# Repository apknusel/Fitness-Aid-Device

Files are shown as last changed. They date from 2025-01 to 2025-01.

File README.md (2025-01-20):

# Wearable Fitness Tracker
## Project Overview
The Wearable Fitness Tracker is a wearable device designed to assist users in monitoring workout intensity and performance. It combines real-time data from a pulse oximeter and a muscle sensor to evaluate heart rate, blood oxygen levels, and muscle engagement. This data is transmitted via Bluetooth Low Energy (BLE) to a web application ([static version of web app](https://apknusel.github.io/WorkoutTracker/)), enabling users to track their exercise sessions efficiently.

## Motivation
The motivation behind this project is trying to find a better way to determine how hard someone is pushing themself while working out. I have seen a lot of people try accelerometers and force sensor to determine how hard someone is working out, but never anyone trying to look at the actual muscle. This was the goal of my project by working with the muscle sensors.

## Key Features
- **Heart Rate and Blood Oxygen Monitoring**: Uses the MAX30102 pulse oximeter for real-time heart rate and SpO2 measurement.
- **Muscle Activity Tracking**: Employs the MyoWare muscle sensor to gauge muscle engagement during exercises.
- **State-Based Operation**: Finite state machine controls device operations with intuitive feedback using a multicolor LED and a vibration motor.
- **Web-Based Interface**: BLE communication with a web application for visualizing and recording fitness data.

## Components

### [Myoware 2.0 Muscle Sensor](https://www.sparkfun.com/products/21265)
- Used for collecting the muscle data. I had to solder one three wires because I was not using a HAT with the device.

### [Vibration Motor](https://www.sparkfun.com/products/8449)
- Used for giving the user feedback to allow the user to use their hands while lifting and not for focusing on the device.

### [MAX30102 Pulse Oximeter](https://www.amazon.com/MAX30102-Detection-Concentration-Compatible-Arduino/dp/B07ZQNC8XP)
- Used for calculating the heart rate and blood oxygen of the person wearing the device

## Circuit Diagram
circuit diagram

## Finite State Machine
The project is designed around a finite state machine with distinct states
- **ON**: Idle state awaiting user input.
- **INITIALIZATION**: Calibrates muscle sensor for baseline readings.
- **READING**: Records muscle engagement data.
- **HRBO**: Measures heart rate and blood oxygen.
- **TRANSMIT**: Sends collected data to the web application.

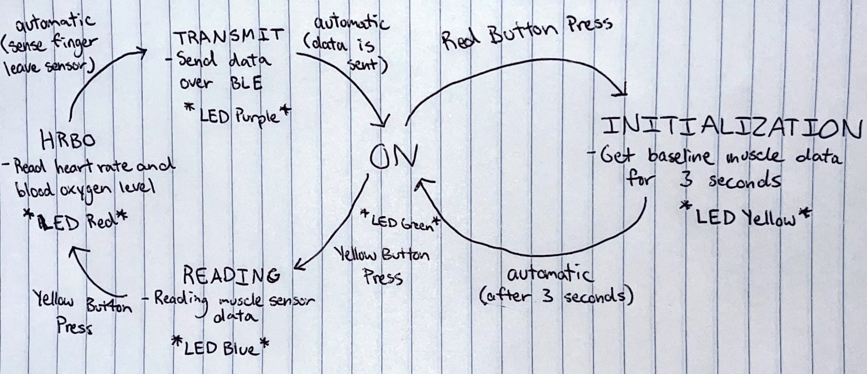
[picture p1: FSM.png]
finite state machine


## Images
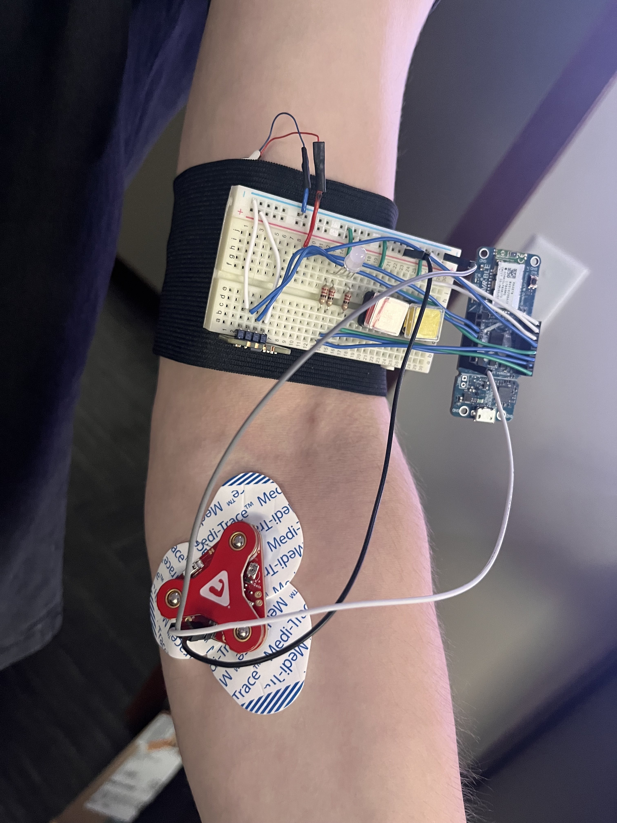
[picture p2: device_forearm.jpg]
device on forearm

device

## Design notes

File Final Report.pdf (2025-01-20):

Alex Knusel

# Final Report: Wearable Fitness Device

## CSCI 5143 - Fall 2024

# Introduction

## What is it?

My project is a fitness device that will aid people in working out by collecting data from various sensors and presenting it in a digestible format for the user. The data collected is from a pulse oximeter (to read heart rate and blood oxygen) and a muscle sensor (to determine a set's percent difficulty or effort). This data is passed into a web application where a user can keep track of the sets and reps for an exercise while the device automatically fills out the heart rate, blood oxygen, time, and percent difficulty. The device aims to answer the question: How hard am I working out? By giving the user easy-to-digest data that can assist in adjusting workouts to get the most out of the time spent at the gym.

## Embedded Systems Relevance

This project showcases the unique characteristics of embedded systems by leveraging their core principles to achieve functionality that distinguishes them from general-purpose desktop computers. Unlike a desktop computer, which is designed for a broad range of tasks, this system is purpose-built for specific applications with a focus on portability, power efficiency, and resource optimization. It incorporates BLE communication, an ADC, and I2C communication with external peripherals, all of which are essential for achieving real-time performance and seamless integration with hardware components. Interrupts for buttons and real-time tracking enhance the system’s responsiveness, enabling immediate interaction with users in ways that a desktop computer cannot efficiently replicate for such specialized tasks.
The use of external peripherals, guided by datasheet interpretation, further showcases the embedded system's adaptability within constrained environments. The system’s compact and portable design makes it more suitable for field use or wearable technology, which would be impractical with a larger computer. Additionally, I incorporated signal processing techniques, such as a DC Estimator and FIR Filter, to process pulse oximeter readings directly on the device, eliminating the need for a full-scale processing system. To extend its functionality, I utilized Node.js to create a lightweight web server for hosting a web application that communicates with the embedded system, bridging the gap between the device and broader networked ecosystems. This holistic approach demonstrates the embedded system's ability to deliver specialized, efficient, and user-friendly solutions in ways that general-purpose computers are not designed to achieve.

# Design and Implementation

## Circuit Diagram

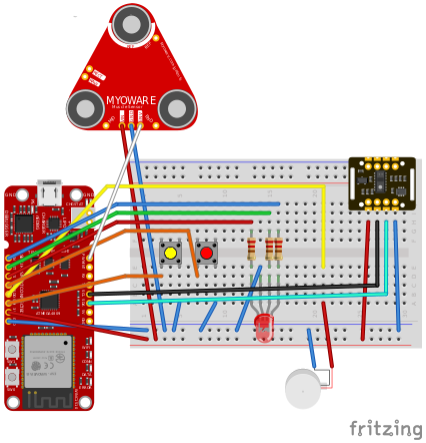
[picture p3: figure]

## Component Connections

### MAX30102 Pulse Oximeter

The MAX30102 pulse oximeter has four pins and uses the I2C communication protocol. The VIN pin is for voltage input, the SDA pin is for serial data, the SCL pin is for the serial clock, and the GND pin is for ground. The peripheral runs on 3.3V per the datasheet.

MAX30102 Pins | AVR-BLE Pins | Diagram Wire Color
VIN | 3.3V | Red
SDA | PA2 (SDA) | Black

SCL | PA3 (SCL) | Teal
GND | GND | Blue

### Multicolor LED

The multicolor LED has four pins: a GND pin for ground and then three pins for controlling the red, green, and blue light intensity based on the current in the circuit. These three pins are also connected to a 220-ohm resistor.

Multicolor LED Pins | AVR-BLE Pins | Diagram Wire Color
Single Leg (Next to Longesr Middle Leg) | D7 | Red
GND (Longest) | GND | GND
Middle Pin (Not Longest) | D5 | Green
Outer Pin (Next to Shorter Middle Leg) | A7 | Blue

### Buttons

There are two buttons, a red button and a yellow button, that are sensed on the rising edge with the internal pullup resistors enabled on the pins. Each button has two pins, one for GPIO and the other for GND.

Button Pins | AVR-BLE Pins | Diagram Wire Color
Red Button - GPIO Pin | A6 | Orange Wire
Red Button - GND | GND | Blue Wire
Yellow Button - GPIO Pin | A4 | Orange Wire
Yellow Button - GND | GND | Blue Wire

### Myoware Muscle Sensor

There are many different pins and configurations for the Myoware Muscle Sensor, but I am connecting to the GND, VIN, and ENV pins on the peripheral. I soldered pins onto the Myoware Muscle Sensor in the location seen in the diagram to connect wires to the board. The power for this peripheral is 3.3V per the datasheet. The ENV pin needs to be connected to a pin that can receive an analog signal, which D1 is capable of. The ENV pin sends the analog signal of the muscle readings from the muscle sensor to the AVR-BLE board.

Muscle Sensor Pins | AVR-BLE Pins | Diagram Wire Color
VIN | 3.3V | Red
GND | GND | Blue
ENV | D1 | White

### Vibration Motor

The vibration motor has two cables attached to it, and I soldered on thicker, longer cables to make it easier to work with. These two wires are GND and VIN.

Vibration Motor Pins | AVR-BLE Pins | Diagram Wire Color
VCC | A5 | Red and Yellow
GND | GND | Blue

## Hardware Setup

My hardware setup uses a few different components of the AVR-BLE board and a few external peripherals. The overall layout of the project is a finite state machine, as shown above, where button presses or an amount of time passing transitions between states. To do this, I used interrupts for button presses on PORTA, and I used the RTC timer with an overflow that triggered at a rate of 1024 Hz, which increases a milliseconds variable by 1000. This is paired with a macro directly accessing the RTC.CNT register and adding that to milliseconds to accurately track time. This is almost perfect, but not quite because RTC.CNT will increment up to 1024 before being reset to 0. That means that if the milliseconds macro is called in the worst case it can be 24 milliseconds off. But once the overflow occurs it resets the RTC.CNT so it will not get less accurate as time goes on. The MAX30102 (pulse oximeter) peripheral is communicated with using I2C communication, and the muscle sensor outputs an analog signal, which the ADC processes. When in the respective state, the functions for interfacing with these devices are called, and data is read in to be transmitted over BLE to the web application later on. When transitioning between states, a short delay gives the user ample time to prepare for the next state. Each state will set the multicolor LED to the color of the respective state, and transitioning between states causes the vibration motor to vibrate so the user does not need to look at the device. The device can be connected to the web application at any point in time, but if it is not connected, it will not send the data anywhere.

If the device is connected to the web application, when the device is in the transmit state, it will send the data to the web app, where the selected row will be populated with the data.

## Hardware Setup Reasoning

There are quite a few reasons why I chose this setup over potential alternatives. I went with using a finite state machine because it is relatively simple to understand and allows for much planning. In this case, the planning was super important because many of my parts did not come until later, so it gave me something to work on while waiting for my parts. I decided to use BLE communication with a web application because it would’ve been very difficult to use a screen or some other medium to display data to the user, especially on a wearable device. Also, the web application is extremely versatile and allows for a database to be hooked up to store data in the future. I also used the web application to test my sensors and understand the data from the external peripherals through graphs. I went with the multicolor LED and vibration sensor because they are both relatively inexpensive, simple components that give the right amount of information to the user. The vibration motor was crucial to making the wearable device reasonable to use while working out because it allows the user to get feedback without looking at the device. This means that after the user presses the button to enter the reading state, they have the vibration to tell them when they can start their exercise to get the most accurate sensor and timer reading. I mainly went with the Myoware muscle sensor because it was the most accessible device to use (cheapest, and there are very few muscle sensors out there). I also originally intended to use it with a HAT that allows it to communicate over BLE, but this was not in stock when ordering parts. Instead, I soldered directly onto the board and used it that way. I looked at a few alternatives, such as using more primitive electronic components to make a “DIY” muscle sensor, but I did not have the electrical experience to carry that out. I decided to use the MAX30102 muscle sensor because it used the I2C protocol and allowed me to do post-processing on the data. However, it had enough QOL features, like a circular buffer, to store a few samples and keep things somewhat simple. This has allowed me to learn a lot more compared to if I used something like the SparkFun Pulse Oximeter and Heart Rate Sensor - MAX30101 & MAX32664 (Qwiic) because a device like this would abstract away the raw data such as IR, red, and green values read by the sensor and only give me the calculated bpm and blood oxygen. I wanted to do these calculations by myself to learn something new.

## Finite State Machine

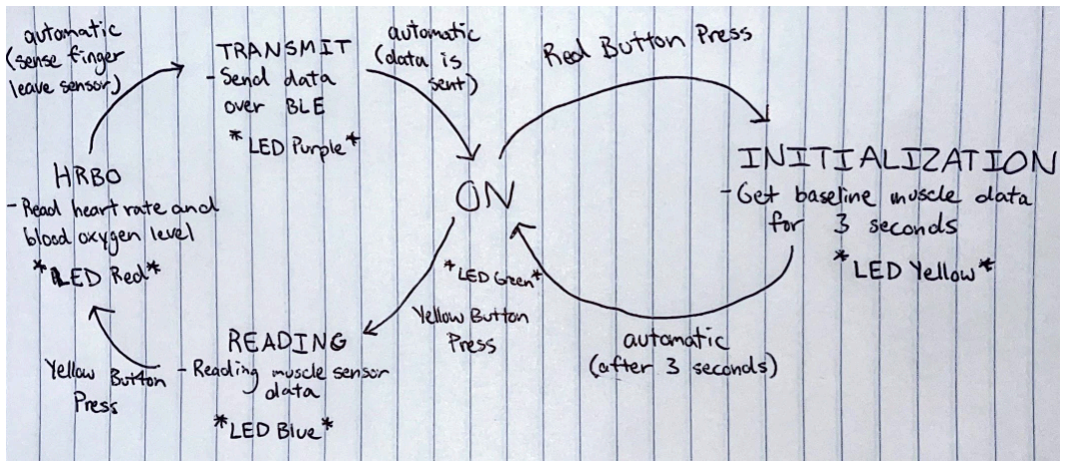
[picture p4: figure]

## Software Key Objectives

- Sensor Data Collection: The software interacts with sensors like the MAX30102 for heart rate and blood oxygen measurement and a muscle sensor for tracking muscle activity. The software needs to be able to read data from these sensors efficiently and timely.
- State Management: The device operates in different states (e.g., ON, INITIALIZATION, READING, HRBO, TRANSMIT), with transitions triggered by button presses or time conditions.
- BLE Communication: The software communicates using the BLE module to send collected data to a web application, enabling monitoring of fitness data. The external web application software needs to be able to accept the data and display it in a userful and convenient way to the user.
- Vibration and LED Control: The device uses vibration to provide feedback to the user and LEDs to indicate the device's current state. The device needs to be able to signal state changes for the user to perform the proper actions in each state in a timely manner.
- Real-time Clock (RTC): The software needs to keep track of time, which is necessary for time-based operations like measuring heart rate intervals or controlling state transitions. This will be an extremely important part of the software that has to be reliable for the device to function properly.
- Web Application: An additional piece of software, the web application, needs to be able to receive information and display it to the user in a digestible format.

## Software Design

- Main Loop: The core loop of the software constantly checks for state changes, manages transitions, collects data, and communicates with the BLE module. It also handles feedback mechanisms like vibrations and LED updates. This paired with the RTC timer allows for timely transitions and correct functioning of the device in each state.
- Interrupts: Various interrupts are used
- Button Press Interrupts: Detect button presses to trigger state transitions.
- RTC Overflow Interrupt: Keeps track of elapsed time by dividing the internal clock that runs at 32.768 kHz by 32 to get a rate of 1.024 kHz. This is as close as you can get the clock to be to 1 kHz which would be ideal for keeping track seconds. I set the RTC.PER value to 1024 so that every second there will be an interrupt. When the interrupt occurs 1000 is added to the milliseconds variable. There is then a micro called millis() defined that adds the milliseconds variable to RTC.CNT to get a relatively accurate number of milliseconds passed since startup. This number was accurate enough for me from what I tested. In the worst-case scenario, this number could be off up to 24 milliseconds because 1 RTC.CNT is equivalent to 0.976 milliseconds instead of 1 millisecond.
- State Management: The device has a state machine (device_state_t) to manage transitions between states such as ON, INITIALIZATION, READING, HRBO, and TRANSMIT.
- ON: This is the initial state of the device and is essentially the waiting state for a button press to transition to a more interesting state.
- INITIALIZATION: Takes a 3 seconds reading of the muscle sensor to get a baseline for future calculations involving the muscle sensor.
- READING: Takes in the data from the muscle sensor and computes a running average of the readings for calculating the percent difficulty.
- HRBO: Takes in data from the MAX30102 pulse oximeter and does calculations to compute the heart rate and blood oxygen.
- TRANSMIT: Sends the heart rate, blood oxygen, percent difficuilty, and time elapsed over BLE to the web application.
- Sensor Data Handling:
- The MAX30102 is used for heart rate and blood oxygen measurement via I2C. It reads in the red and IR values and then uses a DC estimator, FIR filter, and a heart rate and blood oxygen algorithm to calculate the heart rate and blood oxygen.
- The muscle sensor uses ADC to measure muscle activity, and the software processes this data using a running average to determine the intensity of the workout.
- BLE Communication:
- The USART and BLE communication functions are used to initialize the BLE module, send commands, and transfer sensor data over BLE. The BLE module is running the Fitness Machine Service and Physical Activity Level Characteristic which the web application searches for when looking for BLE devices. The characteristic is set with the properties Write, Write Without Response, and Notify.
- Data is sent to the web application in chunks of 8 bytes where each value is 2 bytes long, with each sensor's reading packaged and transmitted through the BLE_send_data function.
- Web Application: The web application receives the chunks of data sent over BLE and applies them to the proper rows associated with that exercise the user is currently doing. This is done by allowing the user to select the row associated with their current exercise. Then, that row is automatically populated when the data is sent.

## Technical Challenges

This project had quite a few technical challenges that needed to be solved. The first of these was how to keep track of time in the software down to milliseconds to do calculations involving heart rate, blood oxygen, and other time-dependent calculations. I used the RTC timer to keep track of elapsed time by dividing the internal clock that runs at 32.768 kHz by 32 to get a rate of 1.024 kHz. This is as close as you can get the clock to be to 1 kHz which would be ideal for keeping track seconds. I set the RTC.PER value to 1024 so that every second there will be an interrupt. When the interrupt occurs 1000 is added to the milliseconds variable. There is then a micro called millis() defined that adds the milliseconds variable to RTC.CNT to get a relatively accurate number of milliseconds passed since startup. This number was accurate enough for me from what I tested. In the worst-case scenario, this number could be off up to 24 milliseconds because 1 RTC.CNT is equivalent to 0.976 milliseconds instead of 1 millisecond.
The second technical challenge needed to be addressed was calculating the heart rate and blood oxygen. I took inspiration from a C++ Arduino Library (https://github.com/sparkfun/SparkFun_MAX3010x_Sensor_Library)

1
for a MAX3010X Sensor to calculate heart rate and adjusted the IR_AC and threshold values to get more accurate readings based on the received data. Calculating heart rate is very difficult, and many external factors can affect the readings. For example, someone's skin color can affect the accuracy of the readings because darker colors absorb more red light. I tuned in the data to calculate my heart rate by graphing the data I received (red value, IR value, and calculated heart rate) while also looking at my Apple Watches heart rate reading. I would adjust the IR_AC values used in the calculations and the thresholds until I got relatively accurate readings. To calculate blood oxygen (SpO2), I followed an article, Oxygen Saturation - SpO2 Measurement (https://community.element14.com/technologies/medical/b/blog/posts/oxygen-saturation---spo2-measurement)

2
, which
detailed some of the higher-level concepts, and then I applied them to my code. I decided not to follow the MAX3010X Arduino libraries method because I wanted to apply what I learned from calculating the heart rate and because blood oxygen was less important data for the user.
Another technical challenge was understanding the muscle sensor readings. This was a challenge for a multitude of reasons. The first reason was that the muscle sensor advertises that it can pick up a wide range of signals based on how much the muscle is flexed, but after testing it myself and reading some discussions online, I realized this is not the case. The muscle can only really reliably tell if a muscle is flexed or not. This, paired with the fact that I was not using a HAT with the sensor, made the data very difficult to read, so I had to interpret the data more similarly to a binary value. This was fine for my application, and I used a running average. After testing the device while working out, the difficulty felt relatively accurate to how I felt after the exercise. Ideally, I would have used a HAT with the device to get the most accurate readings, but the HAT has been out of stock while working on the device.
The last technical challenge I faced was creating an application for the device to communicate with. I messed around with doing this in Python, which I was able to receive data in, but creating a user interface had a large learning curve. This, paired with the overhead and installation process for running the app, made it seem less practical for the average user (one of my goals being to make the device so anyone could use it). My second option was to look at if web browsers support BLE. Fortunately, after reading the following article, Communicating with Bluetooth devices over JavaScript (https://developer.chrome.com/docs/capabilities/bluetooth)

3
, I discoverd they do
and could begin writing code. I hadn’t used JavaScript before this, so I spent some time learning the basics, but eventually, I got the web application working. I decided to use Node.js and Express to run the server and later discovered the simplest solution to allow someone to use the device. This solution was to host the JavaScript application statically on GitHub Pages and allow anyone to test the device at https://apknusel.github.io/WorkoutTracker/

4

# Final Product

## Final Product Pictures

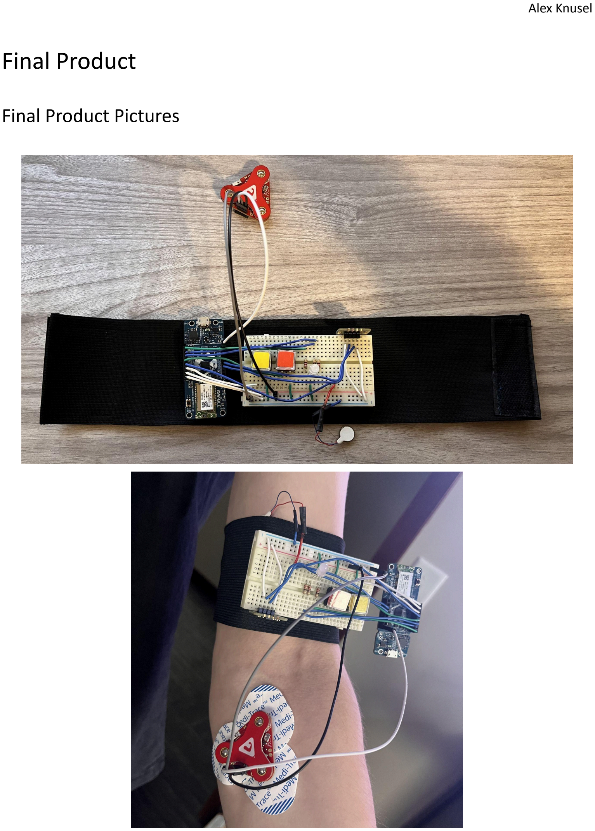
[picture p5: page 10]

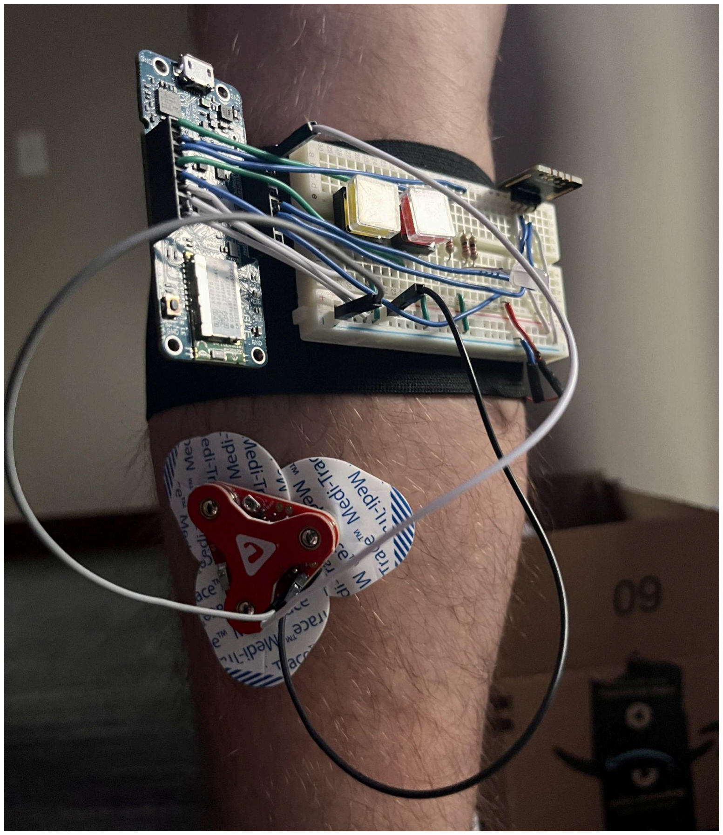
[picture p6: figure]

In the pictures above you can see the device standalone, being worn on the forearm muscle, and being worn on the calf muscle. I managed to get the device to be worn just about everywhere using the black velcro strap and then for larger areas of the body (e.g. across the chest) I could daisy chain together the black straps.

## What is it and How to Use it?

Like I stated earlier in this document the device is a wearable fitness aid the reads in data from a muscle sensor and pulse oximeter and then relays the data over BLE to a web app where a user can track their exercises. This device is designed to allow people to be more efficient with their workouts in the gym and understand if they are working out hard enough. This is important because figuring out if you are working out hard enough is a really difficult task for even some of the most experienced lifters. This is an attempt at solving that problem.
The first step to use the device would be putting on the device which can be done by wrapping the black band on your body near the muscle group you are working out. Then you should attach three EMG/ECG pads to the myoware muscle sensor and figure out based on this guide (https://cdn.sparkfun.com/assets/learn_tutorials/1/9/5/6/MyoWare_v2_AdvancedGuide-Updated.pdf)

5 where to place the
sensor for the muscle you are exercising. Once the sensor is placed on the muscle you can plug in the device to a portable charger using a micro-usb cable to connect to the device. This will power on the device and put it in the ON state. After this, you will open up the fitness tracker and connect the device by entering the device name in the top left. By default this name is FitDev and you will be prompted to select the device and hit pair. Once the device is paired the tracker will display a green disconnect button and you are ready to start working out. Click add exercise on the website and put in the exercise and number of reps you will be doing. Click the select button on that row and it will turn red indicating you selected the row. You will then press the red button on the device and 3 seconds will pass and then you will feel a vibration. Once you feel the vibration you will flex the muscle as hard as you can until you feel another vibration. Once this has finished you get ready to do the exercise for the muscle the sensor is on. Now press the yellow button and once you feel a vibration begin the exercise. Once you are finished with the exercise press the yellow button and place your finger on the pulse oximeter. Once you feel a vibration your heart rate blood oxygen will be read. Leave your finger on the sensor for around 10 seconds or longer for a more accurate reading. Once you finger leaves the sensor 3 seconds will pass and the data will be sent to the web app. If you are switching exercises you will need to repeat the initialization phase by pressing the red button, otherwise you can press the yellow button and select the next row.

## Goals

There were quite a few goals I was able to achieve while working on this project. The first of those goals was creating a functional and simple way to receive data from the device in the style of a fitness tracker. I was able to achieve this goal which can be seen by the functioning web app I created. The second goal I had was to perfect the communication with the MAX30102 pulse oximeter. This was a goal of mine because from reading the datasheet the peripheral was pretty complex. I was able to not only achieve this goal but exceed it by adjusting the algorithms I used for calculating heart rate and blood oxygen to be more accurate. My third goal was to create a form factor that was reasonable to wear while working out. I was able to achieve this goal, but I wish I had more time to 3D print a box for my board and peripherals to make it look more professional.
There were a few initial goals for my project that I did not meet. The first of these goals was to use the accelerometer to collect data as well. I did test this feature and tried to analyse the data in a way that was meaningful to the user. I was not able to figure out a way to do this because every exercise is different and the data didn’t have any real meaning because any exercise could be performed with the device. The second goal I did not meet was making the device extremely accurate. This was a really difficult task and I imagine having some biomedical engineering background could have helped me. I was able to get the blood oxygen very accurate, but the heart rate was ±4 bpm at times when comparing with my Apple Watch readings.

# Reflection

Knowing what I know know now I would’ve made a few changes to the device. The first change I would’ve made is using a more accurate sensor similar to the one another group used when calculating heart rate and blood oxygen. The sensor they had used both fingers and gave much more accurate red and ir values for calculating heart rate and blood oxygen. The second thing I would change is the way I got data from the muscle sensor. Instead of soldering to the ENV, VIN, and GND pins I would’ve used the HAT or instead opted for another approach such as making my own muscle sensor. This would’ve made the data received from the peripheral a lot less noisy.
If I had more time I would focus on making my device more accurate. To make the device more accurate I would try to look at more recent research on calculating heart rate and blood oxygen and implement those algorithms. Another thing I would do to extend the final product would be to reduce the number of buttons or remove them entirely. The buttons were fine, but I think that it would feel much more natural if there was some other mechanism that was more seamless. Maybe even clicking buttons in the web app instead. Lastly, I had begun working on putting the device to sleep in the ON state until a button interrupt occured to switch to another state to try to reduce power consumption, but I have not got that fully working yet.

# References

1. https://github.com/sparkfun/SparkFun_MAX3010x_Sensor_Library
2. https://community.element14.com/technologies/medical/b/blog/posts/oxygen-saturation---spo 2-measurement (https://community.element14.com/technologies/medical/b/blog/posts/oxygen-saturation---spo2-measurement)
3. https://developer.chrome.com/docs/capabilities/bluetooth
4. https://apknusel.github.io/WorkoutTracker/
5. https://cdn.sparkfun.com/assets/learn_tutorials/1/9/5/6/MyoWare_v2_AdvancedGuide-Update d.pdf (https://cdn.sparkfun.com/assets/learn_tutorials/1/9/5/6/MyoWare_v2_AdvancedGuide-Updated.pdf)

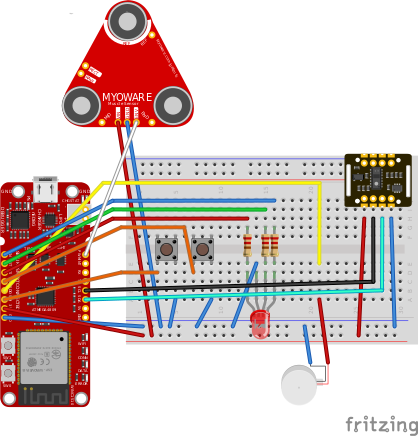
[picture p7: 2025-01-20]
circuit_diagram.png

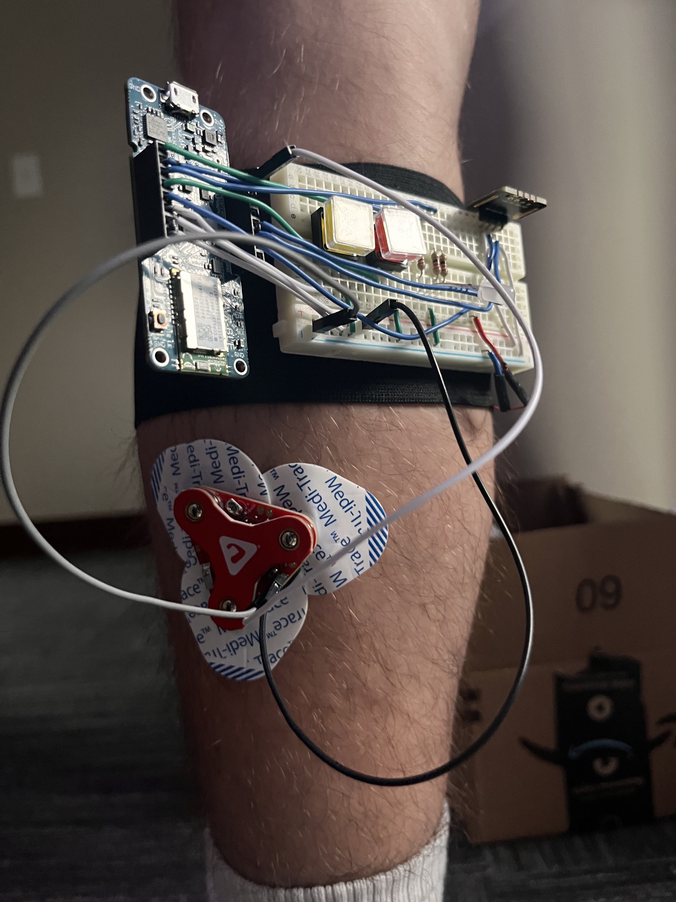
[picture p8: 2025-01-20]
device_calf.jpg

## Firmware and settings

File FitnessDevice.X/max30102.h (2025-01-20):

#ifndef F_CPU
#define F_CPU 3333333
#endif

#include <avr/io.h>
#include <util/delay.h>
#include <stdlib.h>
#include <string.h>
#include <stdio.h>
#include <avr/interrupt.h>
#include "max30102_math.h"

#ifndef MAX30102_H
#define	MAX30102_H

// Definitions for the memory locations on the MAX30102 and valid values
#define MAX30102_I2C_ADDR 0x57

// Constants for default settings
#define DEFAULT_POWER_LEVEL 0x1F
#define DEFAULT_SAMPLE_AVG 4
#define DEFAULT_LED_MODE 3
#define DEFAULT_SAMPLE_RATE 50
#define DEFAULT_PULSE_WIDTH 69
#define DEFAULT_ADC_RANGE 16384

#define MAX30102_FIFO_DATA 0x07

// Status Registers
#define MAX30105_INTSTAT1 0x00
#define MAX30105_INTSTAT2 0x01
#define MAX30105_INTENABLE1	0x02
#define MAX30105_INTENABLE2 0x03

// FIFO Registers
#define MAX30105_FIFOWRITEPTR 0x04
#define MAX30105_FIFOOVERFLOW 0x05
#define MAX30105_FIFOREADPTR 0x06
#define MAX30105_FIFODATA 0x07

// Configuration Registers
#define MAX30105_FIFOCONFIG 0x08
#define MAX30105_MODECONFIG 0x09
#define MAX30105_PARTICLECONFIG 0x0A
#define MAX30105_LED1_PULSEAMP 0x0C
#define MAX30105_LED2_PULSEAMP 0x0D
#define MAX30105_LED3_PULSEAMP 0x0E
#define MAX30105_LED_PROX_AMP 0x10
#define MAX30105_MULTILEDCONFIG1 0x11
#define MAX30105_MULTILEDCONFIG2 0x12

#define MAX30105_DIETEMPINT 0x1F
#define MAX30105_DIETEMPFRAC 0x20
#define MAX30105_DIETEMPCONFIG 0x21

#define MAX30105_PROXINTTHRESH 0x30

#define MAX30105_REVISIONID 0xFE
#define MAX30105_PARTID 0xFF

// MAX30105 Commands
#define MAX30105_INT_A_FULL_MASK 0b10000000
#define MAX30105_INT_A_FULL_ENABLE 0x80
#define MAX30105_INT_A_FULL_DISABLE 0x00

#define MAX30105_INT_DATA_RDY_MASK 0b01000000
#define MAX30105_INT_DATA_RDY_ENABLE 0x40
#define MAX30105_INT_DATA_RDY_DISABLE 0x00

#define MAX30105_INT_ALC_OVF_MASK 0b00100000
#define MAX30105_INT_ALC_OVF_ENABLE 0x20
#define MAX30105_INT_ALC_OVF_DISABLE 0x00

#define MAX30105_INT_PROX_INT_MASK 0b00010000
#define MAX30105_INT_PROX_INT_ENABLE 0x10
#define MAX30105_INT_PROX_INT_DISABLE 0x00

#define MAX30105_INT_DIE_TEMP_RDY_MASK 0b00000010
#define MAX30105_INT_DIE_TEMP_RDY_ENABLE 0x02
#define MAX30105_INT_DIE_TEMP_RDY_DISABLE 0x00

#define MAX30105_SAMPLEAVG_MASK 0b11100000
#define MAX30105_SAMPLEAVG_1 0x00
#define MAX30105_SAMPLEAVG_2 0x20
#define MAX30105_SAMPLEAVG_4 0x40
#define MAX30105_SAMPLEAVG_8 0x60
#define MAX30105_SAMPLEAVG_16 0x80
#define MAX30105_SAMPLEAVG_32 0xA0

#define MAX30105_ROLLOVER_MASK 0xEF
#define MAX30105_ROLLOVER_ENABLE 0x10
#define MAX30105_ROLLOVER_DISABLE 0x00

#define MAX30105_A_FULL_MASK 0xF0

#define MAX30105_SHUTDOWN_MASK 0x7F
#define MAX30105_SHUTDOWN 0x80
#define MAX30105_WAKEUP 0x00

#define MAX30105_RESET_MASK 0xBF
#define MAX30105_RESET 0x40

#define MAX30105_MODE_MASK 0xF8
#define MAX30105_MODE_REDONLY 0x02
#define MAX30105_MODE_REDIRONLY 0x03
#define MAX30105_MODE_MULTILED 0x07

#define MAX30105_ADCRANGE_MASK 0x9F
#define MAX30105_ADCRANGE_2048 0x00
#define MAX30105_ADCRANGE_4096 0x20
#define MAX30105_ADCRANGE_8192 0x40
#define MAX30105_ADCRANGE_16384 0x60

#define MAX30105_SAMPLERATE_MASK 0xE3
#define MAX30105_SAMPLERATE_50 0x00
#define MAX30105_SAMPLERATE_100 0x04
#define MAX30105_SAMPLERATE_200 0x08
#define MAX30105_SAMPLERATE_400 0x0C
#define MAX30105_SAMPLERATE_800 0x10
#define MAX30105_SAMPLERATE_1000 0x14
#define MAX30105_SAMPLERATE_1600 0x18
#define MAX30105_SAMPLERATE_3200 0x1C

#define MAX30105_PULSEWIDTH_MASK 0xFC
#define MAX30105_PULSEWIDTH_69 0x00
#define MAX30105_PULSEWIDTH_118 0x01
#define MAX30105_PULSEWIDTH_215 0x02
#define MAX30105_PULSEWIDTH_411 0x03

#define MAX30105_SLOT1_MASK 0xF8
#define MAX30105_SLOT2_MASK 0x8F
#define MAX30105_SLOT3_MASK 0xF8
#define MAX30105_SLOT4_MASK 0x8F

#define SLOT_NONE 0x00
#define SLOT_RED_LED 0x01
#define SLOT_IR_LED 0x02
#define SLOT_GREEN_LED 0x03
#define SLOT_NONE_PILOT 0x04
#define SLOT_RED_PILOT 0x05
#define SLOT_IR_PILOT 0x06
#define SLOT_GREEN_PILOT 0x07

#define MAX30105_EXPECTEDPARTID 0x15

// Size of buffer for storing samples
#define RATE_SIZE 4

// Struct for collecting sensor data
typedef struct {
    uint32_t ir;
    uint32_t red;
    uint32_t green;
} MAX30102_sample_t;

void MAX30102_bitMask(uint8_t reg, uint8_t mask, uint8_t value);
void MAX30102_softReset();
void MAX30102_setup();
void MAX30102_init();
void MAX30102_buffer_data(uint8_t toGet, uint8_t *buffer);
uint8_t MAX30102_readRegister8(uint8_t reg);
void MAX30102_writeRegister8(uint8_t reg, uint8_t value);
void MAX30102_get_sample(MAX30102_sample_t *sample);
void MAX30102_clearFIFO();
void RTC_init(void);

#endif	/* MAX30102_H */

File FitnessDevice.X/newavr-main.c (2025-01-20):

#ifndef F_CPU
#define F_CPU 3333333
#endif

#include "newavr-main.h"

// Variable that holds the state of the device
volatile device_state_t device_state;

// Variables to implement delay between states and vibration
volatile uint32_t button_press_time = 0; // Time of the button press
volatile bool state_change_pending = false; // Flag for pending state change
volatile device_state_t next_state; // Holds the next state to switch to
volatile uint32_t vibrate_start_time = 0; // Time for when the vibration starts
volatile bool is_vibrating = false; //  Flag for vibration
volatile bool automatic_transition = 0; // Flag for automatic transitions

// Variables for muscle sensor data
volatile uint32_t initialization_start_time = 0; // Start time of the INITIALIZATION state
volatile uint32_t muscle_sum = 0; // Sum of muscle sensor readings
volatile uint32_t muscle_samples = 0; // Number of muscle sensor samples
volatile uint32_t baseline_muscle_average = 0; // Baseline average muscle reading
volatile uint32_t muscle_average = 0; // Average muscle reading

// Variables for calculating heart rate
volatile float average_bpm = 0; // Average beats per minute
volatile float blood_oxygen = 0; // Average blood oxygen level
volatile long lastBeat = 0; // Time since the last beat
volatile float beatsPerMinute = 0; // Current beats per minute
volatile uint8_t rates[RATE_SIZE] = {0}; // Buffer for averaging
volatile uint8_t rateSpot = 0; // Index in rates buffer
volatile uint32_t ir_start_time = 0; // Time when red value exceeded threshold
volatile bool ir_below_threshold = false; // Tracks if red value is above threshold

// Buffer for storing the data to send over BLE
volatile uint16_t data_to_send[4];

// Amount of time in the READING state
volatile uint32_t reading_time = 0;

// Variable to hold milliseconds since startup
volatile uint32_t milliseconds = 0;

/**
* Initialize the vibrating peripheral
*/
void vibration_init() {
   PORTA.DIR |= PIN5_bm;
}

/**
* Starts the vibrating peripheral
*/
void start_vibration() {
   PORTA.OUTSET = PIN5_bm; // Set A5 high
   vibrate_start_time = millis();  // Record the start time
   is_vibrating = true; // Mark vibration as active
}

/**
* Checks if the device is vibrating and cancels it after 500 ms
*/
void check_vibrate() {
   if (is_vibrating) {
       // Check if 500 ms have elapsed
       if (millis() - vibrate_start_time >= 500) {
           PORTA.OUTCLR = PIN5_bm; // Set A5 low (turn off output)
           is_vibrating = false; // Reset the state
       }
   }
}

/**
* Initializes the RTC timer
*/
void RTC_init(void) {
   // Select RTC clock source
   RTC.CLKSEL = RTC_CLKSEL_INT32K_gc;

   // Configure RTC: Enable, run in standby, prescaler = 32 so 1024 Hz
   RTC.CTRLA = RTC_PRESCALER_DIV32_gc | RTC_RUNSTDBY_bm | RTC_RTCEN_bm;

   // Enable overflow interrupt
   RTC.INTCTRL = RTC_OVF_bm;

   // Start from zero
   RTC.CNT = 0;
   
   // Interrupt every second
   RTC.PER = 1024;
}

/**
* Collects the muscle data from the muscle sensor peripheral
* @param average holds the average reading for the muscle sensor
* @param timed if the function should run for 3 seconds or until state change
*/
void collect_muscle_data(uint32_t *average, bool timed) {
   // Start initialization process
   if (initialization_start_time == 0) {
       initialization_start_time = millis(); // Record the start time
       muscle_sum = 0;
       muscle_samples = 0;
   }


   // If timed is true and 3 seconds have elapsed, finalize data collection,
   // otherwise a button press will end this looping
   if (timed && millis() - initialization_start_time >= 3000) {
        if (muscle_samples > 0) {
            *average = muscle_sum / muscle_samples; // Update the variable passed as an argument
            set_LED_color(0, 1, 0);
            start_vibration();
        } else {
            *average = 0; // Set to 0 if no samples were collected
        }
        // Reset for future use if stopping after 3 seconds
        initialization_start_time = 0;
        next_state = ON;
        automatic_transition = true;
   } else {
       muscle_sum += ADC_read();
       muscle_samples++;
   }
}

/**
* Updates the variables passed in with the correct data for the HR and BO
* @param average_bpm variable to hold the average beats per minute
* @param blood_oxygen variable to hold the average blood oxygen
*/
void sense_HRBO(float *average_bpm, float *blood_oxygen) {
   MAX30102_sample_t sample;
   MAX30102_get_sample(&sample);

   // Heart rate calculation
   if (check_for_beat(sample.ir)) {
       uint32_t delta = millis() - lastBeat;
       lastBeat = millis();

       beatsPerMinute = 60 / (delta / 1000.0);

       if (beatsPerMinute < 255 && beatsPerMinute > 20) {
           rates[rateSpot++] = (uint8_t)beatsPerMinute;
           rateSpot %= RATE_SIZE;

           // Calculate the average BPM
           *average_bpm = 0;
           for (uint8_t i = 0; i < RATE_SIZE; i++) {
               *average_bpm += rates[i];
           }
           *average_bpm /= RATE_SIZE;
           // Blood oxygen calculation
           calculate_and_update_spo2(&blood_oxygen, sample.ir, sample.red);
       }
   }

   // Transition to TRANSMIT state if red value < 50000 for 3 seconds
   if (sample.ir < 50000) {
        if (!ir_below_threshold) {
            ir_start_time = millis(); // Start timing
            ir_below_threshold = true;
        } else if (millis() - ir_start_time >= 3000) {
            set_LED_color(1, 0, 1); // Set LED to Purple
            ir_below_threshold = false; // Reset tracking
            ir_start_time = 0;
            next_state = TRANSMIT; // Transition to TRANSMIT state
            automatic_transition = true;
        }
   } else {
       // Reset if red value drops below threshold
       ir_below_threshold = false;
       ir_start_time = 0;
   }
}

/**
 * Resets all the variables that need to be rest in between readings
 */
void reset_globals() {
    muscle_average = 0;
    average_bpm = 0;
    blood_oxygen = 0;
    reading_time = 0;
    lastBeat = 0;
    beatsPerMinute = 0;
    rateSpot = 0;
    ir_start_time = 0;
    ir_below_threshold = false;
    initialization_start_time = 0;
    for (uint8_t i = 0; i < RATE_SIZE; i++) {
        rates[i] = 0;
    }
}
/**
* Port interrupt service routine for button press/release
*/
ISR(PORTA_PORT_vect) {
   if (RED_BUTTON_INTERRUPT) {
       if (device_state == ON && !state_change_pending) {
           button_press_time = millis(); // Record button press time
           next_state = INITIALIZATION; // Set the next state
           state_change_pending = true; // Indicate a pending state change
       }
       RED_BUTTON_INTERRUPT_CLEAR;
   }

   if (YELLOW_BUTTON_INTERRUPT) {
       if ((device_state == ON || device_state == READING || device_state == HRBO) && !state_change_pending) {
           state_change_pending = true; // Indicate a pending state change
           button_press_time = millis(); // Record button press time
           switch (device_state) {
               case ON:
                   next_state = READING;
                   reading_time = millis();
                   break;
               case READING:
                   next_state = HRBO;
                   reading_time = millis() - reading_time;
                   break;
               case HRBO:
                   next_state = TRANSMIT;
                   break;
           }
       }
       YELLOW_BUTTON_INTERRUPT_CLEAR;
   }
}

/**
* RTC interrupt to keep track of system time
*/
ISR(RTC_CNT_vect) {
   // Overflow is trigger every 1000 ms
   milliseconds += 1000;
   RTC.INTFLAGS = RTC_OVF_bm; // Clear overflow flag
}

/**
* Main function to initialize and run the code
*/
int main() {
   // Initializations
   USART_init();
   RTC_init();
   ADC_init();
   MAX30102_init();
   MAX30102_setup();
   button_init();
   vibration_init();
   LED_init();
   BLE_init("FitDev");
   
   // Enable interrupts
   sei();
   
   // Initialize to ON state;
   device_state = ON;
   set_LED_color(0, 1, 0); // Green

   while (1) {
       // Check if a state change is pending and if the delay has elapsed
       if ((state_change_pending && (millis() - button_press_time >= 3000)) || automatic_transition) {
            device_state = next_state; // Switch to the next state
            state_change_pending = false; // Reset the flag
            automatic_transition = false;
            start_vibration();

            // Change the LED based on the new state
            switch (device_state) {
                case ON:
                    set_LED_color(0, 1, 0); // Green
                    break;
                case INITIALIZATION:
                    set_LED_color(1, 1, 0); // Yellow
                    break;
                case READING:
                    set_LED_color(0, 0, 1); // Blue
                    break;
                case HRBO:
                    set_LED_color(1, 0, 0); // Red
                    break;
                case TRANSMIT:
                    set_LED_color(1, 0, 1); // Purple
                    break;
            }
        }
       // Check if the device should vibrate
       check_vibrate();
       
       // General brains of the code to determine what to do in each state
       switch (device_state) {
           case ON:
               break;
           case INITIALIZATION:
               collect_muscle_data(&baseline_muscle_average, true);
               break;
           case READING:
               collect_muscle_data(&muscle_average, false);
               break;
           case HRBO:
               sense_HRBO(&average_bpm, &blood_oxygen);
               break;
           case TRANSMIT:
               data_to_send[0] = muscle_average/baseline_muscle_average*100;
               data_to_send[1] = average_bpm;
               data_to_send[2] = blood_oxygen;
               data_to_send[3] = reading_time / 1000;
               BLE_send_data(data_to_send, 4);
               set_LED_color(0, 1, 0); // Set color to green
               next_state = ON;
               automatic_transition = true;
               reset_math_globals();
               reset_globals();
               break;
       }
   }
}
